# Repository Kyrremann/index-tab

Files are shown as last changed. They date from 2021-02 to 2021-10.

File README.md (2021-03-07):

Index Tab
---------

 Index Tab is a 6x13 ortho keyboard. Tried to make it look like index tab that are used as dividers in drawers and
 ring binders. The reason for 13 in width instead of 12 is that I’m Norwegian, and neeed that added row for `æøå`.

 You can play around with the layout over at [Keyboard Layout Editor](http://www.keyboard-layout-editor.com/#/gists/2577189f7cf19d980fff8177d14dc3ec).

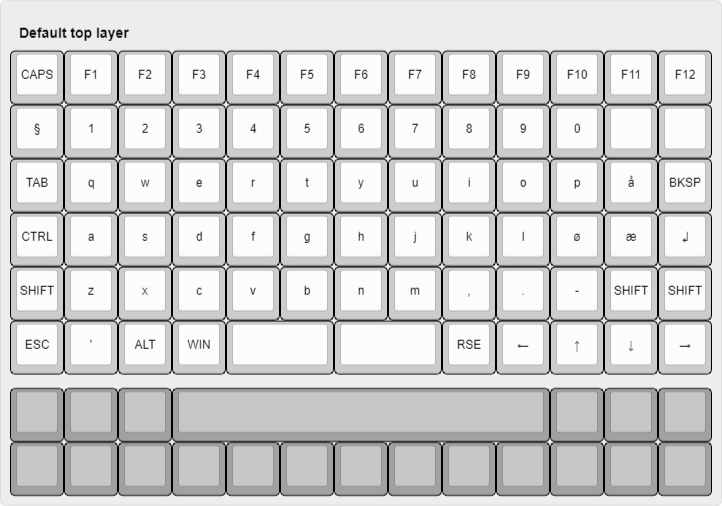
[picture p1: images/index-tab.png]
the current keymap


## Diary

### [rev5] - 2021-03-07

It's over a year since I started on this project. I had problem soldering rev4, so decided to copy the MCU laytout from
[evyd13/plain60-c](https://github.com/evyd13/plain60-c) and pay for SMT assembly. I also had to fix the spacer holes,
as they where too small for the spacers. The size was for a M2 screw. It's been changed to a 5mm hole. The OLED screen
has also been removed, firstly because I choose the wrong component (so the holes where way too small), and I don't
really like the look of the OLED screens.

Another big change is the change to the keyboard layout, I've removed the swiss cheeze bottom. Decided to just go for a
simple 1u only row, 2x2u, or 7u bottom-row. Now you can use clip-in stabilizers. Does didn't fit the swiss cheese row.

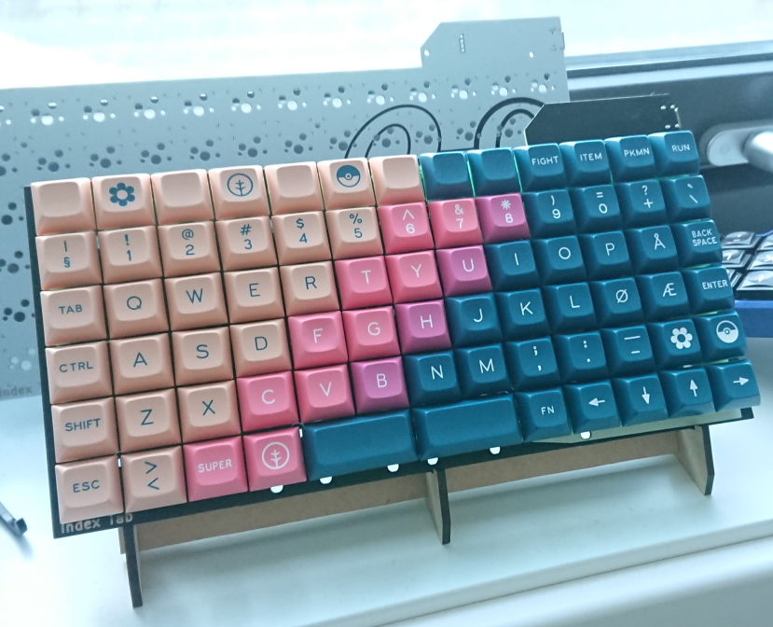
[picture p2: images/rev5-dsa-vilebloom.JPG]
Rev5 with switches and keycaps - DSA Vilebloom


### [rev4] - 2020-06-10

The original plan was to be done with the project with revision 3, but looking at what I wanted to use the keyboard for,
I decided to add a OLED screen to it. By doing that I could make a cool and simple keyboard switcher, with information
about each switch. Will probably be a lot of work to get that to work, so we'll see if it ever will be made.

Another thing I wanted to try out, as can be seen in PCB and layout images, is the swiss cheese bottom row. It started
with me adding the stabs hole that should have been in rev1, and then adding more and more, too see if it is possible!
And yes, it is possible with a lot of holes, the issue I've discovedred now, is that the stabs are not fitting as good,
because there are so many hole next to each other, and overlapping.

There will be one more revision before I'm saying I'm done, but that will just be to fix the small m2 screw holes for
mounting, that should have been m2 spacers holes. Major mistake there...

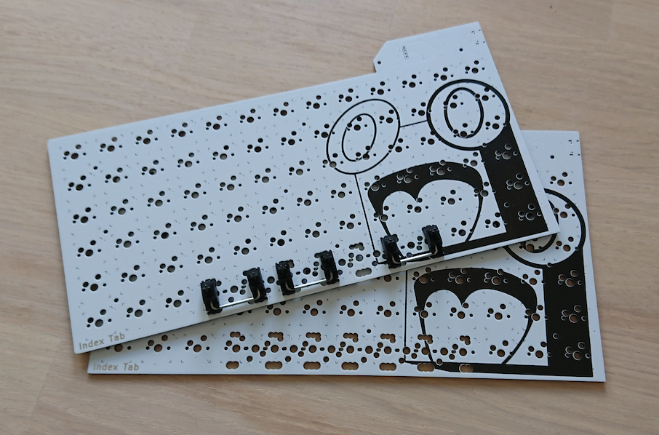
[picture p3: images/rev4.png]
A rev4 pcb with some stabilizers


### [rev2] - 2020-04-10

It's going slow, like most of the world right now. I ordered the second revision before I managed to get the first one
working as I was a bit afraid there where something wrong with my design, plus I was sick and tired of debugging it.

Revision 2 was ordered 30th of March, and it arrived a week after that, and it took me until now to write how it's
gone. I can start of by saying it finally work! It didn't work at first, and it didn't work before I changed the
capacitators for the crystal to something lower. I had originally just used the same crystal and capacitators as the
[UT47.2](https://github.com/ai03-2725/UT47.2/), but it turnes out to not work for the bigger ATMEGA-32U4 chip (compared
to the smaller ATMEGA-32U2 chip). After good tips from both Slack and Discord, I tried a lower capacitator, going from
22pF down to 14pF, which is more correct if your using a "Load Capacitance formula", check out this
[Adafruit](https://blog.adafruit.com/2012/01/24/choosing-the-right-crystal-and-caps-for-your-design/) article to learn
more.

From the image below you can see that I haven't made a proper case for it yet, mostly because I'm not used to working
with Inkscape, but I should be able to make a sandwich case with the tab on the top, other then that it's not much more
to do for the Index Tab. I am planning a third revision, adding arrows for the diode silk print, adding holes for the
stabs, and maybe making the space bar "area" more customizable.

A completed version of the rev2

### [rev1] - 2020-02-28

Yesterday I received the PCB for my first keyboard. It's looks better then expected, and I'm pleased with the form
factor that I choose. I also had time to solder the important bits, aka the micro controller, to see if it works.

Sadly, it looks like it doesn't. There is no connection with the Atmega-chip, and I have no idea why. There are 
several possibilities for this, so I need to do further debugging. One highly plausible reason is that there is 
bad connection with the crystal, as the footprint I choose doesn't really fit with the crystal that I ordered.

Another thing I found out is that I used a 0603 foot print for my diodes, instead of the normal SOD-123, so
that is at least one thing that needs to be fixed in the next version.

I've also decided to drop  the schottky-diode, as it turns out I really don't need it. I'm also thorn about
keeping the power led that I've added. It's nice to see that the board is powered, but it's also pretty visible
if you have RGB-leds, or just by typing. It kinda just add to the design, without being necessary.

Another foot print that I want to change is the USB-C, as I'd like to order all parts from DigiKey, instead of
ordering the USB-C from LCSC and the rest from DigiKey.

Other then that there are some minor design changes I would like to do. Align all the RGBs with each other, and align
all the diode at the bottom of the foot prints for the switches. Also, the holes for the switch legs where really(!) 
thight. That should probably need to be fixed.

That's all for now. Probably going to make a seperate blog for my keyboards, as I want to write about the
[Akihabare 40](https://www.thingiverse.com/thing:3105838) and [Apoptosis](https://github.com/pseudoku/Apoptosis)
keyboards I ordered at the same time as my Index Tab.

The printed v0.1 PCB

### Renders

For now I've got some simple renders from Kicad, enjoy!

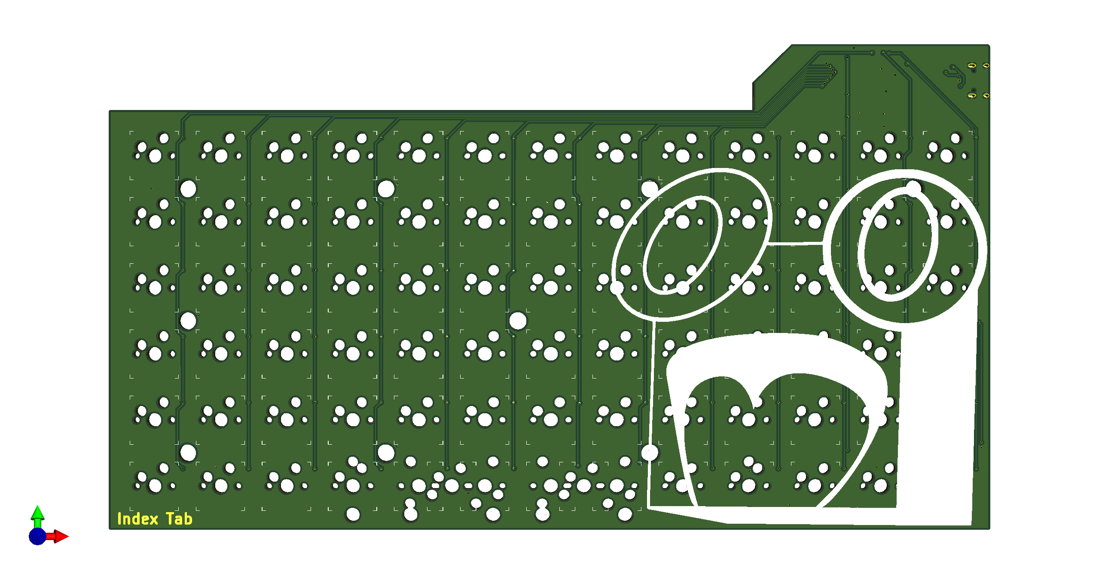
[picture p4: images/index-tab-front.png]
the front side


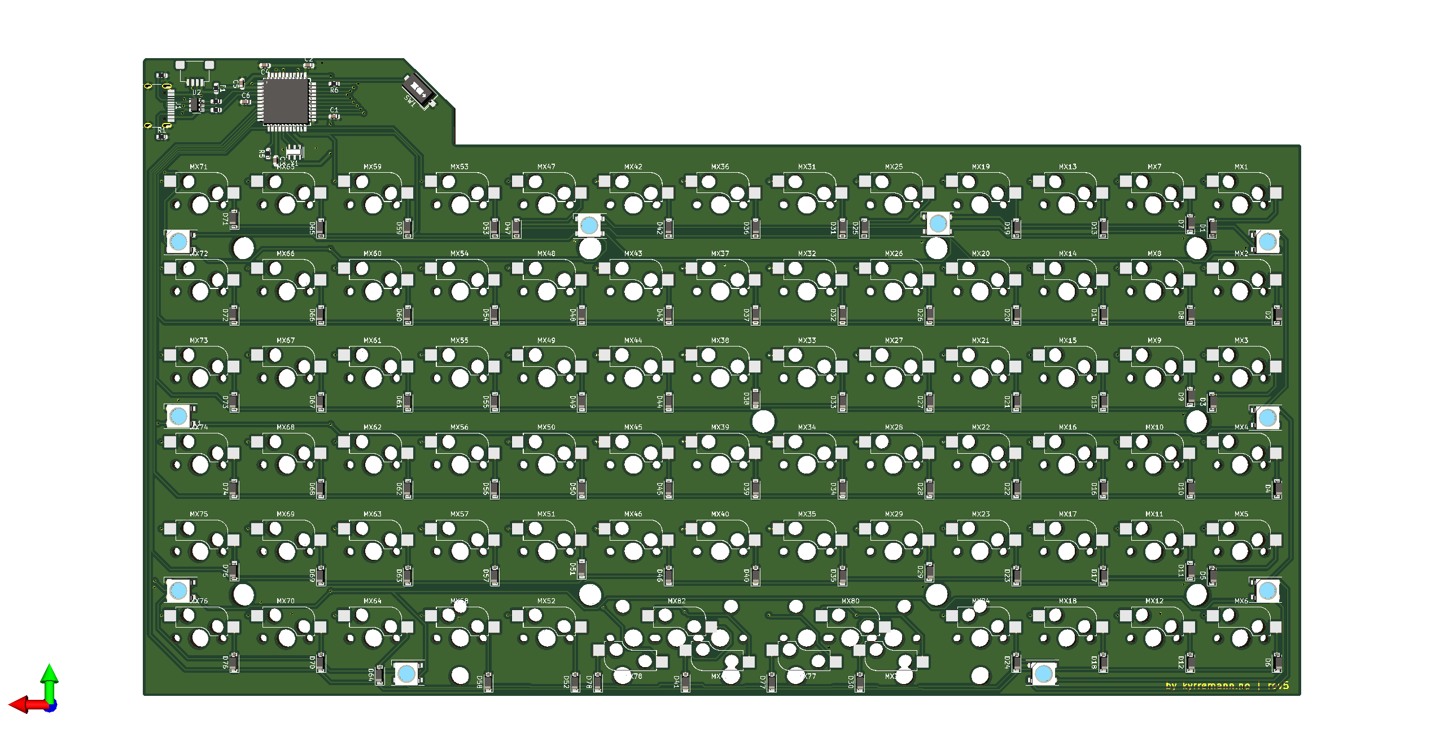
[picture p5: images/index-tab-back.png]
the back side


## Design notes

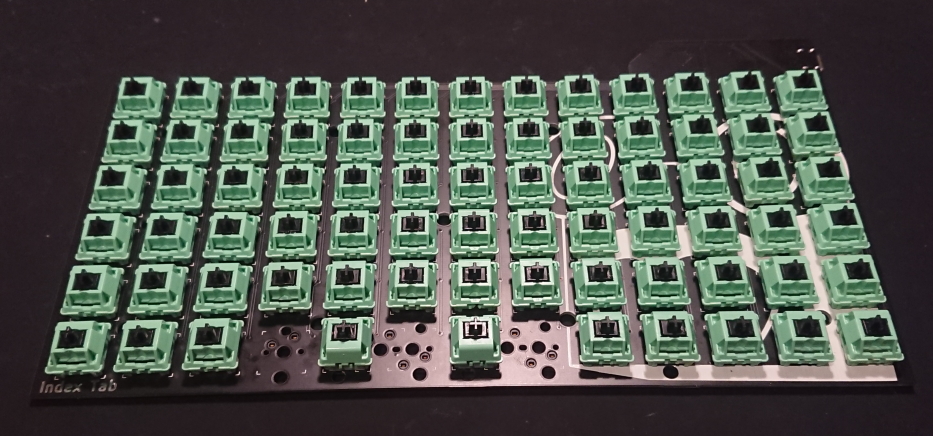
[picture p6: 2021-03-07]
images/rev5-with-switches.JPG

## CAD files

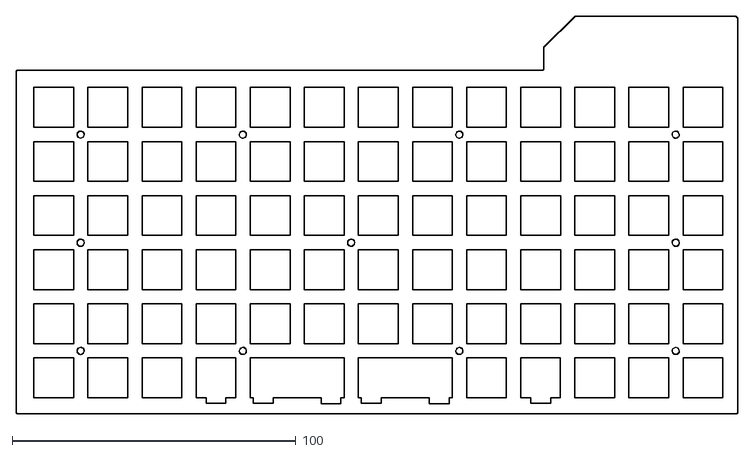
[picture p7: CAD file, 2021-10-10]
case/switch-plate.dxf
254.0 x 140.0

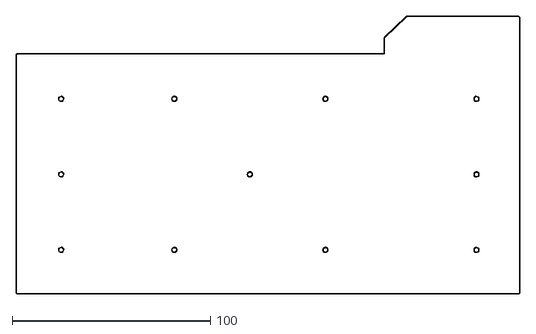
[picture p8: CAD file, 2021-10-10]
case/back-plate.dxf
254.0 x 140.0

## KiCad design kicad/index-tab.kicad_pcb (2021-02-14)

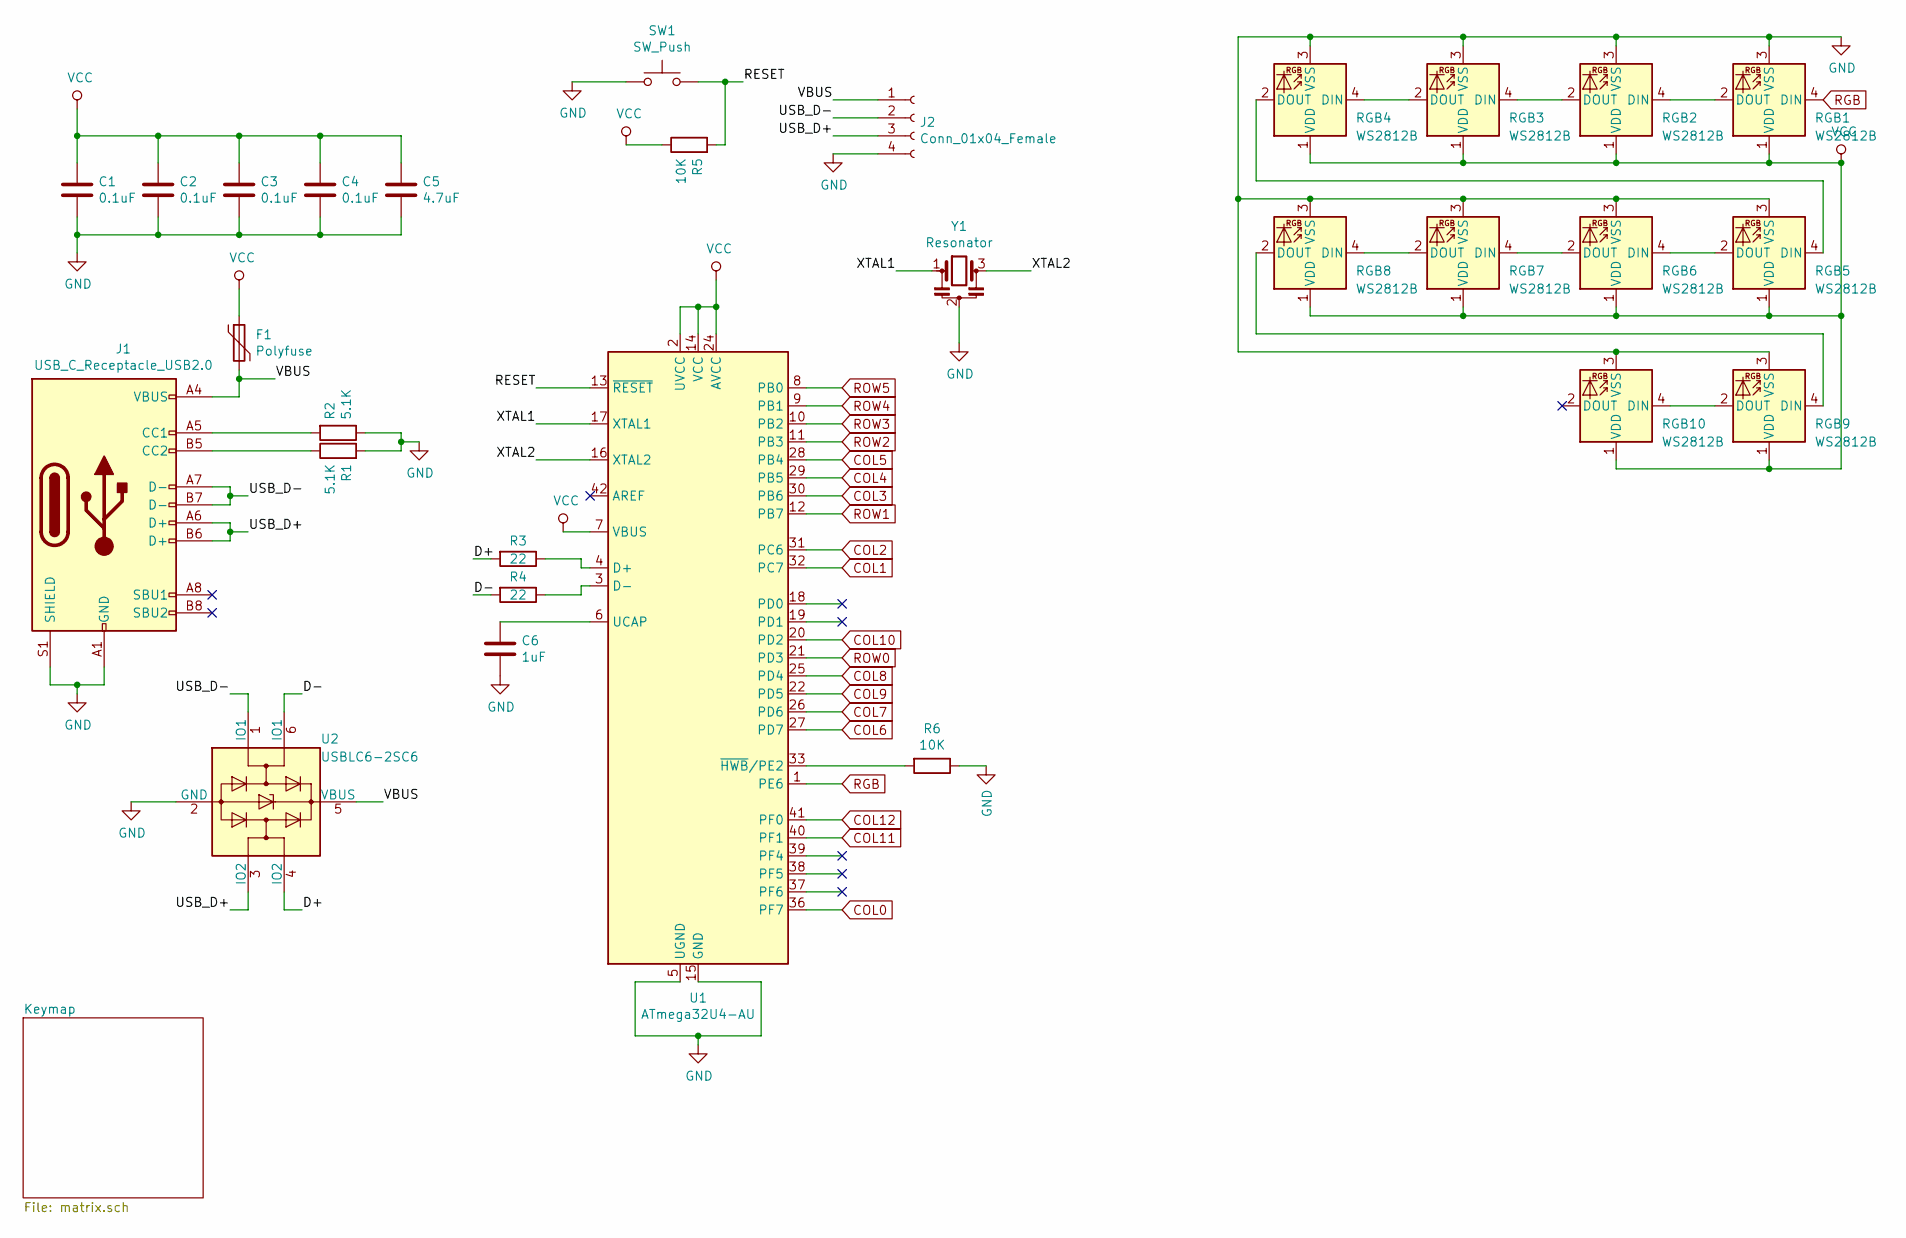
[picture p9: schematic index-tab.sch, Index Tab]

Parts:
C1, C2, C3, C4: 0.1uF; C_0603_1608Metric
C5: 4.7uF; C_0603_1608Metric
C6: 1uF; C_0603_1608Metric
F1: Polyfuse; Fuse_0603_1608Metric
J1: USB_C_Receptacle_USB2.0; USB_C_Receptacle_HRO_TYPE-C-31-M-12
J2: Conn_01x04_Female; JST_SH_SM04B-SRSS-TB_1x04-1MP_P1.00mm_Horizontal
R1, R2: 5.1K; R_0603_1608Metric
R3, R4: 22; R_0603_1608Metric
R5, R6: 10K; R_0603_1608Metric
RGB1, RGB2, RGB3, RGB4, RGB5, RGB6, RGB7, RGB8, RGB9, RGB10: WS2812B; LED_WS2812B_PLCC4_5.0x5.0mm_P3.2mm
SW1: SW_Push; SW_DIP_SPSTx01_Slide_6.7x4.1mm_W6.73mm_P2.54mm_LowProfile_J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
U1: ATmega32U4-AU; TQFP-44_10x10mm_P0.8mm
U2: USBLC6-2SC6; SOT-23-6
Y1: Resonator; Resonator_SMD_muRata_CSTxExxV-3Pin_3.0x1.1mm_HandSoldering

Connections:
/D+: R3.2, U2.4 (IO2)
/D-: R4.2, U2.6 (IO1)
/RESET: R5.2, SW1.2, U1.13 (~RESET)
/USB_D+: J1.A6 (D+), J1.B6 (D+), J2.3, U2.3 (IO2)
/USB_D-: J1.A7 (D-), J1.B7 (D-), J2.2, U2.1 (IO1)
/VBUS: F1.2, J1.A4 (VBUS), J1.A9 (VBUS), J1.B4 (VBUS), J1.B9 (VBUS), J2.1, U2.5 (VBUS)
/XTAL1: U1.17 (XTAL1), Y1.1
/XTAL2: U1.16 (XTAL2), Y1.3
COL0: U1.36 (PF7); also elsewhere on the board
COL1: U1.32 (PC7); also elsewhere on the board
COL2: U1.31 (PC6); also elsewhere on the board
COL3: U1.30 (PB6); also elsewhere on the board
COL4: U1.29 (PB5); also elsewhere on the board
COL5: U1.28 (PB4); also elsewhere on the board
COL6: U1.27 (PD7); also elsewhere on the board
COL7: U1.26 (PD6); also elsewhere on the board
COL8: U1.25 (PD4); also elsewhere on the board
COL9: U1.22 (PD5); also elsewhere on the board
COL10: U1.20 (PD2); also elsewhere on the board
COL11: U1.40 (PF1); also elsewhere on the board
COL12: U1.41 (PF0); also elsewhere on the board
GND: C1.2, C2.2, C3.2, C4.2, C5.2, C6.1, J1.A1 (GND), J1.A12 (GND), J1.B1 (GND), J1.B12 (GND), J1.S1 (SHIELD), J2.4, R1.2, R2.1, R6.1, RGB1.3 (VSS), RGB2.3 (VSS), RGB3.3 (VSS), RGB4.3 (VSS), RGB5.3 (VSS), RGB6.3 (VSS), RGB7.3 (VSS), RGB8.3 (VSS), RGB9.3 (VSS), RGB10.3 (VSS), SW1.1, U1.5 (UGND), U1.15 (GND), U1.23 (GND), U1.35 (GND), U1.43 (GND), U2.2 (GND), Y1.2
unnamed: C6.2, U1.6 (UCAP)
unnamed: J1.A5 (CC1), R2.2
unnamed: J1.B5 (CC2), R1.1
unnamed: R3.1, U1.4 (D+)
unnamed: R4.1, U1.3 (D-)
unnamed: R6.2, U1.33 (~HWB~/PE2)
unnamed: RGB1.2 (DOUT), RGB2.4 (DIN)
unnamed: RGB2.2 (DOUT), RGB3.4 (DIN)
unnamed: RGB3.2 (DOUT), RGB4.4 (DIN)
unnamed: RGB4.2 (DOUT), RGB5.4 (DIN)
unnamed: RGB5.2 (DOUT), RGB6.4 (DIN)
unnamed: RGB6.2 (DOUT), RGB7.4 (DIN)
unnamed: RGB7.2 (DOUT), RGB8.4 (DIN)
unnamed: RGB8.2 (DOUT), RGB9.4 (DIN)
unnamed: RGB9.2 (DOUT), RGB10.4 (DIN)
RGB: RGB1.4 (DIN), U1.1 (PE6)
ROW0: U1.21 (PD3); also elsewhere on the board
ROW1: U1.12 (PB7); also elsewhere on the board
ROW2: U1.11 (PB3); also elsewhere on the board
ROW3: U1.10 (PB2); also elsewhere on the board
ROW4: U1.9 (PB1); also elsewhere on the board
ROW5: U1.8 (PB0); also elsewhere on the board
VCC: C1.1, C2.1, C3.1, C4.1, C5.1, F1.1, R5.1, RGB1.1 (VDD), RGB2.1 (VDD), RGB3.1 (VDD), RGB4.1 (VDD), RGB5.1 (VDD), RGB6.1 (VDD), RGB7.1 (VDD), RGB8.1 (VDD), RGB9.1 (VDD), RGB10.1 (VDD), U1.2 (UVCC), U1.7 (VBUS), U1.14 (VCC), U1.24 (AVCC), U1.34 (VCC), U1.44 (AVCC)

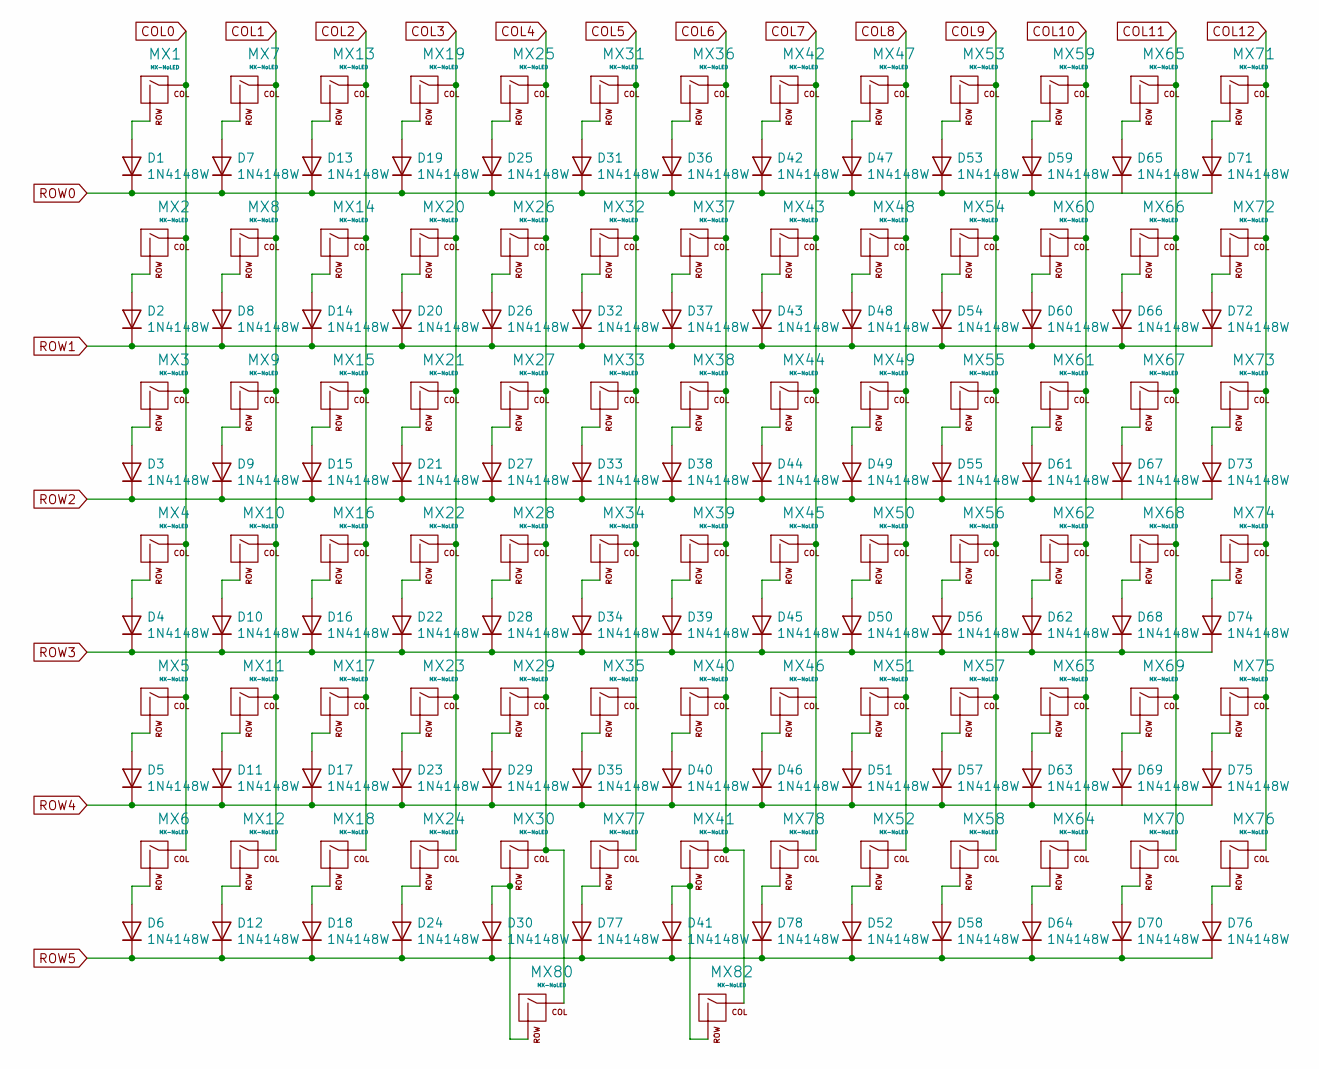
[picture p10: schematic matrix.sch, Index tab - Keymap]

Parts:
D1, D2, D3, D4, D5, D6, D7, D8, D9, D10, D11, D12, D13, D14, D15, D16, D17, D18, D19, D20, D21, D22, D23, D24, D25, D26, D27, D28, D29, D30, D31, D32, D33, D34, D35, D36, D37, D38, D39, D40, D41, D42, D43, D44, D45, D46, D47, D48, D49, D50, D51, D52, D53, D54, D55, D56, D57, D58, D59, D60, D61, D62, D63, D64, D65, D66, D67, D68, D69, D70, D71, D72, D73, D74, D75, D76, D77, D78: 1N4148W; D_SOD-123
MX1, MX2, MX3, MX4, MX5, MX6, MX7, MX8, MX9, MX10, MX11, MX12, MX13, MX14, MX15, MX16, MX17, MX18, MX19, MX20, MX21, MX22, MX23, MX24, MX25, MX26, MX27, MX28, MX29, MX30, MX31, MX32, MX33, MX34, MX35, MX36, MX37, MX38, MX39, MX40, MX41, MX42, MX43, MX44, MX45, MX46, MX47, MX48, MX49, MX50, MX51, MX52, MX53, MX54, MX55, MX56, MX57, MX58, MX59, MX60, MX61, MX62, MX63, MX64, MX65, MX66, MX67, MX68, MX69, MX70, MX71, MX72, MX73, MX74, MX75, MX76, MX77, MX78, MX80, MX82: MX-NoLED; Kailh_socket_MX

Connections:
COL0: MX1.1 (COL), MX2.1 (COL), MX3.1 (COL), MX4.1 (COL), MX5.1 (COL), MX6.1 (COL); also elsewhere on the board
COL1: MX7.1 (COL), MX8.1 (COL), MX9.1 (COL), MX10.1 (COL), MX11.1 (COL), MX12.1 (COL); also elsewhere on the board
COL2: MX13.1 (COL), MX14.1 (COL), MX15.1 (COL), MX16.1 (COL), MX17.1 (COL), MX18.1 (COL); also elsewhere on the board
COL3: MX19.1 (COL), MX20.1 (COL), MX21.1 (COL), MX22.1 (COL), MX23.1 (COL), MX24.1 (COL); also elsewhere on the board
COL4: MX25.1 (COL), MX26.1 (COL), MX27.1 (COL), MX28.1 (COL), MX29.1 (COL), MX30.1 (COL), MX80.1 (COL); also elsewhere on the board
COL5: MX31.1 (COL), MX32.1 (COL), MX33.1 (COL), MX34.1 (COL), MX35.1 (COL), MX77.1 (COL); also elsewhere on the board
COL6: MX36.1 (COL), MX37.1 (COL), MX38.1 (COL), MX39.1 (COL), MX40.1 (COL), MX41.1 (COL), MX82.1 (COL); also elsewhere on the board
COL7: MX42.1 (COL), MX43.1 (COL), MX44.1 (COL), MX45.1 (COL), MX46.1 (COL), MX78.1 (COL); also elsewhere on the board
COL8: MX47.1 (COL), MX48.1 (COL), MX49.1 (COL), MX50.1 (COL), MX51.1 (COL), MX52.1 (COL); also elsewhere on the board
COL9: MX53.1 (COL), MX54.1 (COL), MX55.1 (COL), MX56.1 (COL), MX57.1 (COL), MX58.1 (COL); also elsewhere on the board
COL10: MX59.1 (COL), MX60.1 (COL), MX61.1 (COL), MX62.1 (COL), MX63.1 (COL), MX64.1 (COL); also elsewhere on the board
COL11: MX65.1 (COL), MX66.1 (COL), MX67.1 (COL), MX68.1 (COL), MX69.1 (COL), MX70.1 (COL); also elsewhere on the board
COL12: MX71.1 (COL), MX72.1 (COL), MX73.1 (COL), MX74.1 (COL), MX75.1 (COL), MX76.1 (COL); also elsewhere on the board
unnamed: D1.2 (A), MX1.2 (ROW)
unnamed: D2.2 (A), MX2.2 (ROW)
unnamed: D3.2 (A), MX3.2 (ROW)
unnamed: D4.2 (A), MX4.2 (ROW)
unnamed: D5.2 (A), MX5.2 (ROW)
unnamed: D6.2 (A), MX6.2 (ROW)
unnamed: D7.2 (A), MX7.2 (ROW)
unnamed: D8.2 (A), MX8.2 (ROW)
unnamed: D9.2 (A), MX9.2 (ROW)
unnamed: D10.2 (A), MX10.2 (ROW)
unnamed: D11.2 (A), MX11.2 (ROW)
unnamed: D12.2 (A), MX12.2 (ROW)
unnamed: D13.2 (A), MX13.2 (ROW)
unnamed: D14.2 (A), MX14.2 (ROW)
unnamed: D15.2 (A), MX15.2 (ROW)
unnamed: D16.2 (A), MX16.2 (ROW)
unnamed: D17.2 (A), MX17.2 (ROW)
unnamed: D18.2 (A), MX18.2 (ROW)
unnamed: D19.2 (A), MX19.2 (ROW)
unnamed: D20.2 (A), MX20.2 (ROW)
unnamed: D21.2 (A), MX21.2 (ROW)
unnamed: D22.2 (A), MX22.2 (ROW)
unnamed: D23.2 (A), MX23.2 (ROW)
unnamed: D24.2 (A), MX24.2 (ROW)
unnamed: D25.2 (A), MX25.2 (ROW)
unnamed: D26.2 (A), MX26.2 (ROW)
unnamed: D27.2 (A), MX27.2 (ROW)
unnamed: D28.2 (A), MX28.2 (ROW)
unnamed: D29.2 (A), MX29.2 (ROW)
unnamed: D30.2 (A), MX30.2 (ROW), MX80.2 (ROW)
unnamed: D31.2 (A), MX31.2 (ROW)
unnamed: D32.2 (A), MX32.2 (ROW)
unnamed: D33.2 (A), MX33.2 (ROW)
unnamed: D34.2 (A), MX34.2 (ROW)
unnamed: D35.2 (A), MX35.2 (ROW)
unnamed: D36.2 (A), MX36.2 (ROW)
unnamed: D37.2 (A), MX37.2 (ROW)
unnamed: D38.2 (A), MX38.2 (ROW)
unnamed: D39.2 (A), MX39.2 (ROW)
unnamed: D40.2 (A), MX40.2 (ROW)
unnamed: D41.2 (A), MX41.2 (ROW), MX82.2 (ROW)
unnamed: D42.2 (A), MX42.2 (ROW)
unnamed: D43.2 (A), MX43.2 (ROW)
unnamed: D44.2 (A), MX44.2 (ROW)
unnamed: D45.2 (A), MX45.2 (ROW)
unnamed: D46.2 (A), MX46.2 (ROW)
unnamed: D47.2 (A), MX47.2 (ROW)
unnamed: D48.2 (A), MX48.2 (ROW)
unnamed: D49.2 (A), MX49.2 (ROW)
unnamed: D50.2 (A), MX50.2 (ROW)
unnamed: D51.2 (A), MX51.2 (ROW)
unnamed: D52.2 (A), MX52.2 (ROW)
unnamed: D53.2 (A), MX53.2 (ROW)
unnamed: D54.2 (A), MX54.2 (ROW)
unnamed: D55.2 (A), MX55.2 (ROW)
unnamed: D56.2 (A), MX56.2 (ROW)
unnamed: D57.2 (A), MX57.2 (ROW)
unnamed: D58.2 (A), MX58.2 (ROW)
unnamed: D59.2 (A), MX59.2 (ROW)
unnamed: D60.2 (A), MX60.2 (ROW)
unnamed: D61.2 (A), MX61.2 (ROW)
unnamed: D62.2 (A), MX62.2 (ROW)
unnamed: D63.2 (A), MX63.2 (ROW)
unnamed: D64.2 (A), MX64.2 (ROW)
unnamed: D65.2 (A), MX65.2 (ROW)
unnamed: D66.2 (A), MX66.2 (ROW)
unnamed: D67.2 (A), MX67.2 (ROW)
unnamed: D68.2 (A), MX68.2 (ROW)
unnamed: D69.2 (A), MX69.2 (ROW)
unnamed: D70.2 (A), MX70.2 (ROW)
unnamed: D71.2 (A), MX71.2 (ROW)
unnamed: D72.2 (A), MX72.2 (ROW)
unnamed: D73.2 (A), MX73.2 (ROW)
unnamed: D74.2 (A), MX74.2 (ROW)
unnamed: D75.2 (A), MX75.2 (ROW)
unnamed: D76.2 (A), MX76.2 (ROW)
unnamed: D77.2 (A), MX77.2 (ROW)
unnamed: D78.2 (A), MX78.2 (ROW)
ROW0: D1.1 (K), D7.1 (K), D13.1 (K), D19.1 (K), D25.1 (K), D31.1 (K), D36.1 (K), D42.1 (K), D47.1 (K), D53.1 (K), D59.1 (K), D65.1 (K), D71.1 (K); also elsewhere on the board
ROW1: D2.1 (K), D8.1 (K), D14.1 (K), D20.1 (K), D26.1 (K), D32.1 (K), D37.1 (K), D43.1 (K), D48.1 (K), D54.1 (K), D60.1 (K), D66.1 (K), D72.1 (K); also elsewhere on the board
ROW2: D3.1 (K), D9.1 (K), D15.1 (K), D21.1 (K), D27.1 (K), D33.1 (K), D38.1 (K), D44.1 (K), D49.1 (K), D55.1 (K), D61.1 (K), D67.1 (K), D73.1 (K); also elsewhere on the board
ROW3: D4.1 (K), D10.1 (K), D16.1 (K), D22.1 (K), D28.1 (K), D34.1 (K), D39.1 (K), D45.1 (K), D50.1 (K), D56.1 (K), D62.1 (K), D68.1 (K), D74.1 (K); also elsewhere on the board
ROW4: D5.1 (K), D11.1 (K), D17.1 (K), D23.1 (K), D29.1 (K), D35.1 (K), D40.1 (K), D46.1 (K), D51.1 (K), D57.1 (K), D63.1 (K), D69.1 (K), D75.1 (K); also elsewhere on the board
ROW5: D6.1 (K), D12.1 (K), D18.1 (K), D24.1 (K), D30.1 (K), D41.1 (K), D52.1 (K), D58.1 (K), D64.1 (K), D70.1 (K), D76.1 (K), D77.1 (K), D78.1 (K); also elsewhere on the board

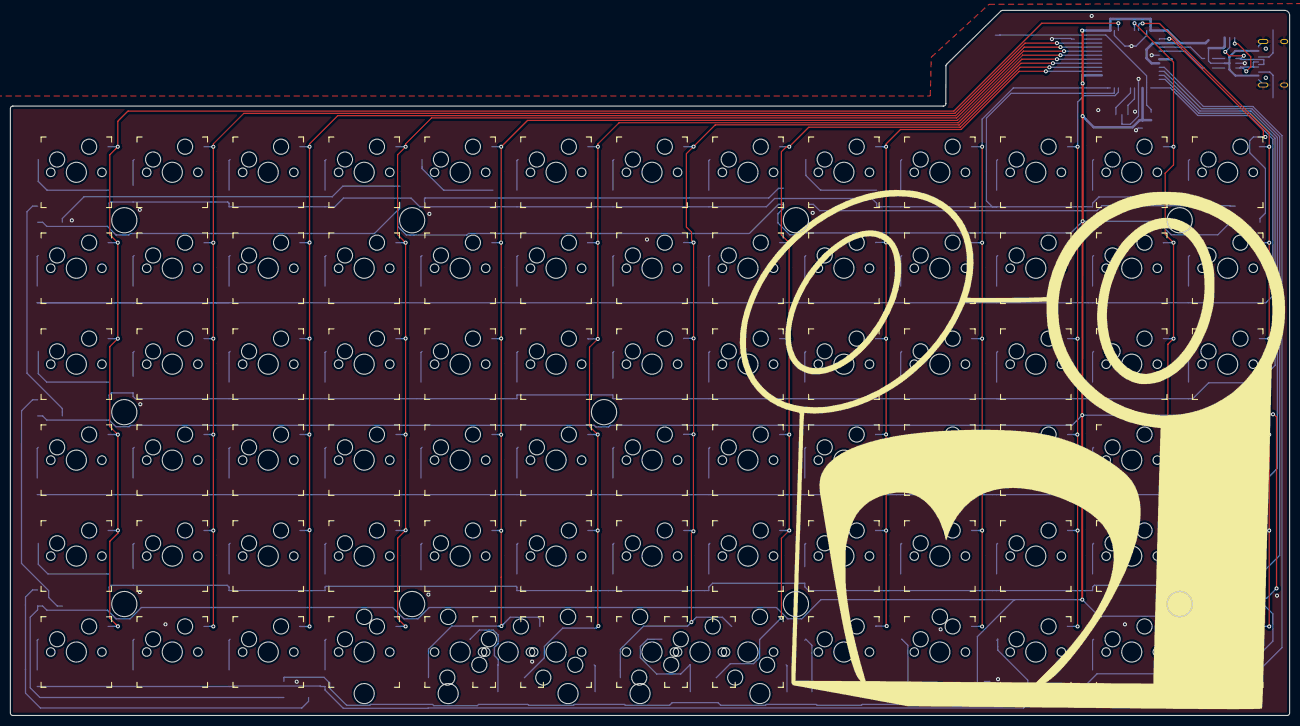
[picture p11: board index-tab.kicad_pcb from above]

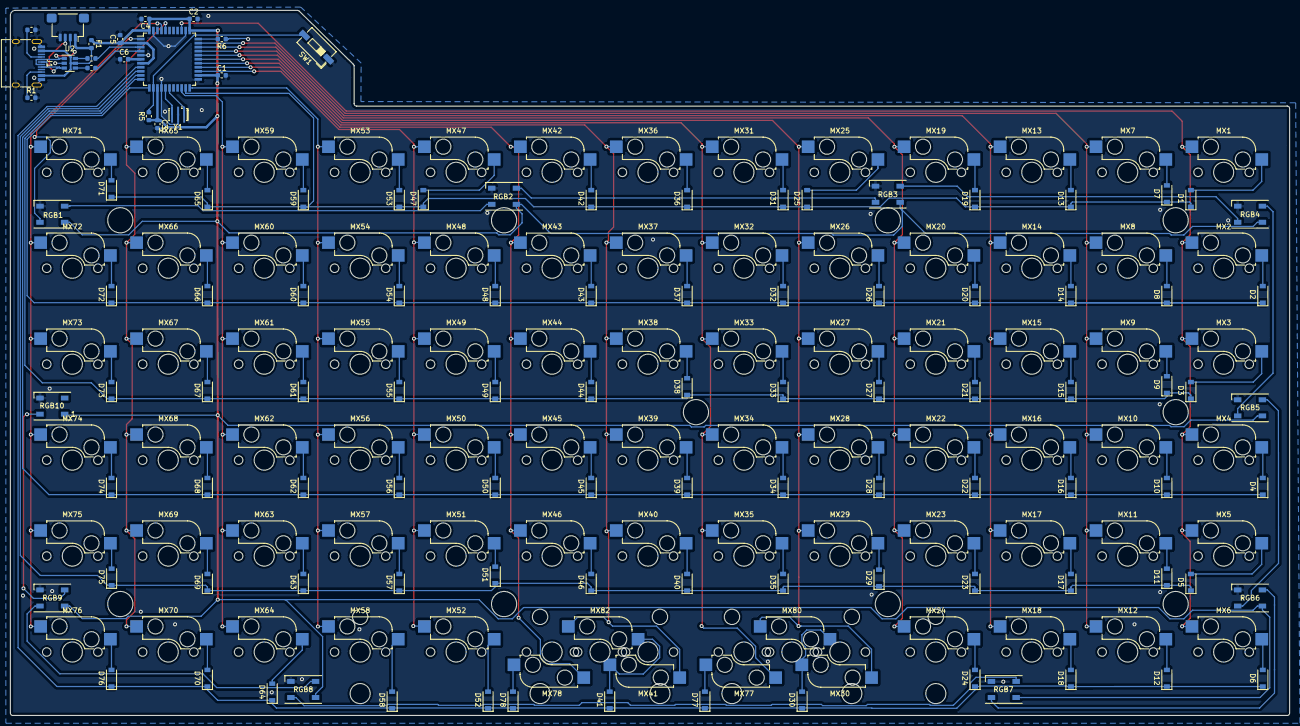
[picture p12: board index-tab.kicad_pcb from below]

Board: 2 copper layers, 254.0 x 140.0 mm, 190 parts (107 on the bottom side), 123 nets.

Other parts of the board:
STAB1: 7u; MXOnly-7U-Hotswap
STAB2, STAB3: 2u; Stabilizer_MX_2u

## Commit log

2020-02-06 Init commit
    Started small, with atmega-chip and usb-c. Not sure if it's working, but it's a start.
    [index-tab.kicad_pcb, index-tab.sch, matrix.sch]
2020-02-07 Updated somevalues, and fixed the pin layout
    [index-tab.sch]
2020-02-09 Added MX alps hybrid symbol to the library
    [matrix.sch]
2020-02-09 Trying to make the library path indepented
    [matrix.sch]
2020-02-09 Change to u4, added files for backlight and rgb
    [backlight.sch, index-tab.sch, matrix.sch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]
2020-02-10 changed some labels, and hopefully done with the atmega32u4 changes
    [index-tab.sch]
2020-02-10 added backlight and rgb
    [backlight.sch, rgb.sch]
2020-02-10 Added footprints to all components, and done some formatting
    [backlight.sch, index-tab.kicad_pcb, index-tab.sch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]
2020-02-17 Working PCB, plus images
    [index-tab.kicad_pcb, index-tab.sch, matrix.sch]
2020-02-17 Renamed folder
    [backlight.sch, index-tab.kicad_pcb, index-tab.sch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]
2020-02-17 Should not be here
    [matrix.sch]
2020-02-19 Not SOT-143B footprint in Kicad
2020-02-19 Switched to 0603 and redrawn the PCB
    [index-tab.kicad_pcb, index-tab.sch, matrix.sch]
2020-02-19 Added rounded corners to the pcb
    [index-tab.kicad_pcb]
2020-02-19 Moved some components for better fillzone
    [index-tab.kicad_pcb]
2020-02-19 Added RGB and a monster to the f.silk
    [index-tab.kicad_pcb, index-tab.sch]
2020-02-28 The gerber sent to production
    [index-tab-B_Cu.gbr, index-tab-B_Mask.gbr, index-tab-B_SilkS.gbr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]
2020-02-29 Changed diode footprint to the more used sod-123
    [matrix.sch]
2020-02-29 Moved diode and rgb footprint
    Need to create new traces too, but later
    [index-tab.kicad_pcb]
2020-03-04 Retraced and rebuild the PCB
    Fixed wrong footprint for diodes and crystal. Trying out a new USB-C, but probably changing back before order of rev2. Also added ESD for safty.
    [index-tab.kicad_pcb, index-tab.sch]
2020-03-06 Changed USB-C and added more gnd
    Suing the easier HRO TYPE-C-31-M-12
    [index-tab.kicad_pcb, index-tab.sch]
2020-03-08 rev2 ordered
    this was done before I've managed to get rev1 working. Post coming about it. rev2 looks more like UT47.2
    [index-tab-B_Cu.gbr, index-tab-B_Mask.gbr, index-tab-B_SilkS.gbr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]
2020-05-02 Added stabs and fixed text
    [index-tab.kicad_pcb]
2020-05-03 rotated all the rgb so they face the same direction
    [index-tab.kicad_pcb]
2020-05-03 Added screw holes to the board
    Will make it easier to make better cases
    [index-tab.kicad_pcb]
2020-05-03 Fixed ugly trace
    [index-tab.kicad_pcb]
2020-05-03 Updated gerber for rev3
    [index-tab-B_Cu.gbr, index-tab-B_Mask.gbr, index-tab-B_SilkS.gbr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]
2020-05-11 added revision number
    [index-tab.kicad_pcb, index-tab.sch]
2020-05-11 added bom for all three revisions
2020-05-23 Adding crazy many options for bottom row
    this is going to be rev4
    [index-tab.kicad_pcb, matrix.sch]
2020-05-24 finished adding stabs
    There is no way to many possiblities at the bottom row
    [index-tab.kicad_pcb, matrix.sch]
2020-05-24 OLED screen added
    [index-tab.kicad_pcb, index-tab.sch]
2020-05-24 Changed the mountin hole
    Can now have a seperate plate for the oled/top. Also added the monster head back in
    [index-tab.kicad_pcb, index-tab.sch]
2021-02-12 rev4: I think
    This is so old I'm not really sure what it is. Going to make rev5 anyway, so just ignore this.
    [index-tab-B_Cu.gbr, index-tab-B_Mask.gbr, index-tab-B_SilkS.gbr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]
2021-02-12 rev5: updated schematic
    This is heavily inspired by Plain60 by evyd13
    [index-tab.kicad_pcb, index-tab.sch, matrix.sch]
2021-02-13 rev5: MCU schematic and pcb should be done
    [index-tab.kicad_pcb, index-tab.sch]
2021-02-13 rev5: fixed 2x2u and 7u stabs
    [index-tab.kicad_pcb, index-tab.sch, matrix.sch]
2021-02-14 rev5: fixed mounting holes
    This time they are of the correct size for spacers!
    [index-tab.kicad_pcb, index-tab.sch]
2021-02-14 rev5: minor fixes after feedback
    Flipped 2u switch, as that will probably be main layout, so no problems with gateron switches
    Some vias was a bit to close to diodes
    Made gnd pads for jst bigger for easier soldering
    [index-tab.kicad_pcb]
2021-02-14 rev5: ready for production
    [index-tab-B_Cu.gbr, index-tab-B_Mask.gbr, index-tab-B_SilkS.gbr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]
2021-03-07 rev5: updated bom
2021-03-07 rev5: files should just be in the release
    [index-tab-bom.xlsx]
2021-10-10 feat: added case files
    [back-plate.dxf, switch-plate.dxf]
